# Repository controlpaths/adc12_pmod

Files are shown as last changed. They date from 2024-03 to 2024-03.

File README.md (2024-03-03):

# PMOD ADC12

PMOD with an ADC and an analog circuit to read signals up to +-12V. The PMOD uses the ADC [ADC122S021](https://www.ti.com/lit/ds/symlink/adc122s021.pdf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) from TI.

To read negative signals, the analog circuit inserts an offset voltage before the signal in connected to the ADC. This offset is always VCC/2. 

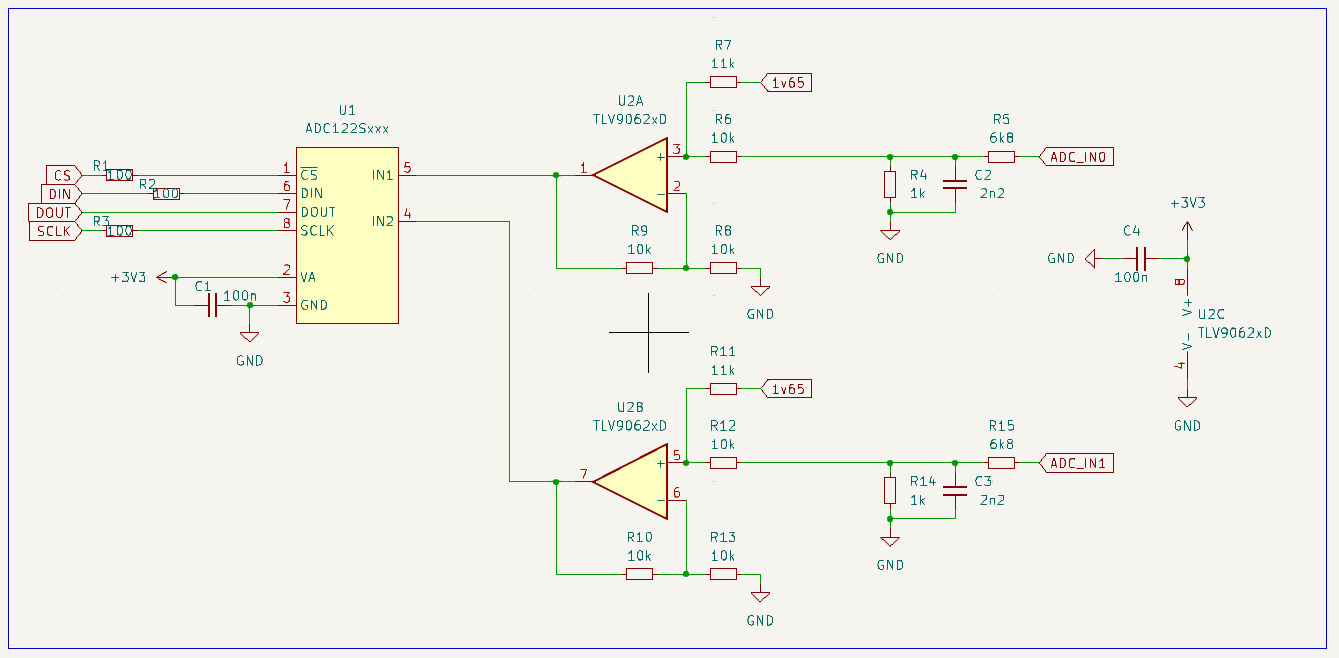
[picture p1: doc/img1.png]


In addition, a first-order low pass filter is added in both input channels.

## PMOD interface

This PMOD uses an SPI interface to read the ADC. The pinout of the board is shown in the next image.

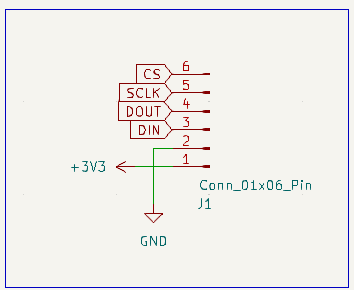
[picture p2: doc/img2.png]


The SPi connection is different than the PMOD SPI standard.

## Images

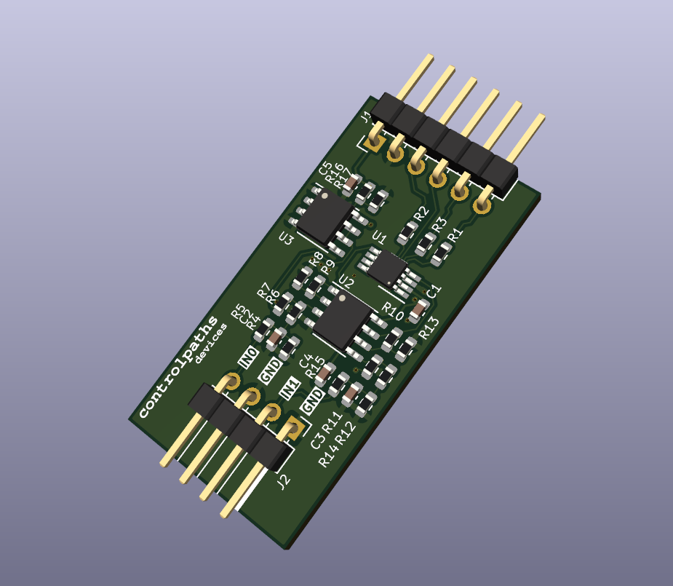
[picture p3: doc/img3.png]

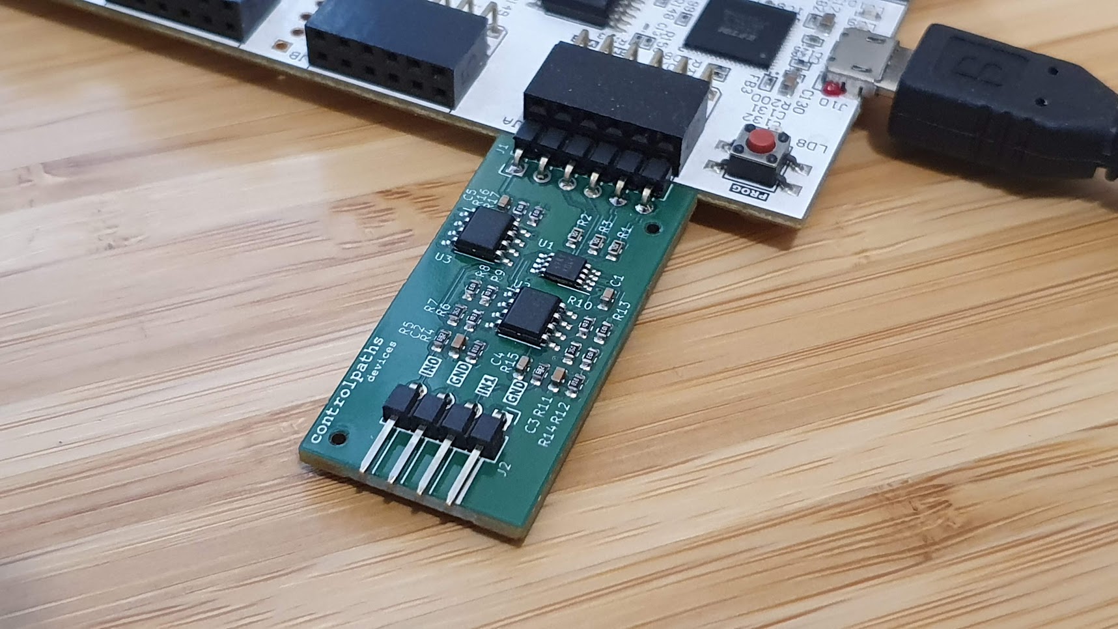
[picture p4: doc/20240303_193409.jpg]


## Get Yours

The PMOD ADC12 is open-source, so you can use the output files to manufacture your own in [JLCPCB](https://jlcpcb.com/?from=controlpath). You just need to compress the `output_files` directory, and upload it to [JLCPCB](https://jlcpcb.com/?from=controlpath). 

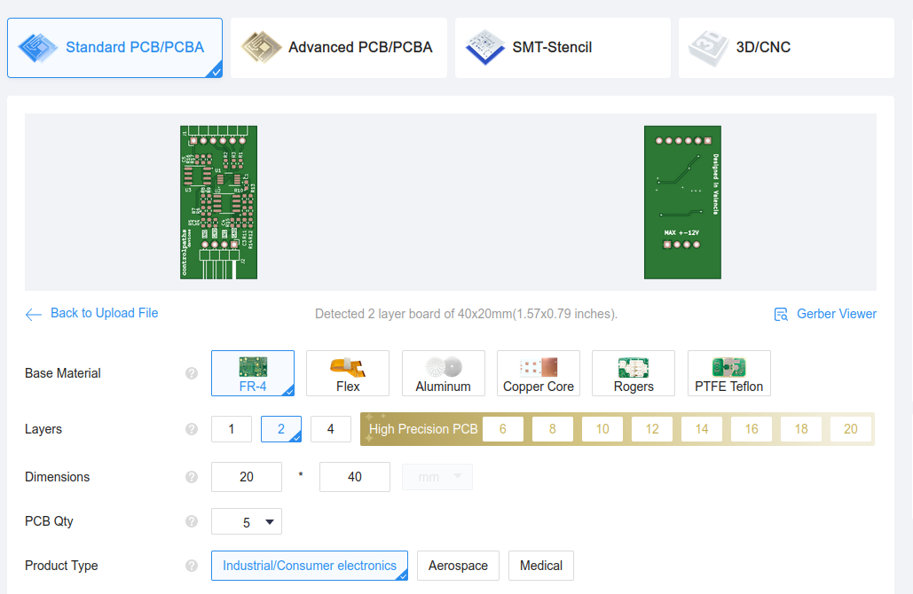
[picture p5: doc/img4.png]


Remember to change the Surface Finish to **LeadFree HASL** to make your board ROHS compliant.

Then you have to add the PCB Assembly service and upload the [centroid](./kicad/output_files/pmod_adc12-all-pos.csv) file, and the [BOM](./kicad/output_files/bom.csv). 

In a few days, you will receive your board at home. If you want just one PMOD ADC12, contact me.

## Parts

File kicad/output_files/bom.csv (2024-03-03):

# | Reference | Qty | Value | Footprint | DNP | JLCPCB Part #
1 | C1, C4, C5 | 3 | 100n | Capacitor_SMD:C_0603_1608Metric
2 | C2, C3 | 2 | 2n2 | Capacitor_SMD:C_0603_1608Metric
3 | J1 | 1 | Conn_01x06_Pin | Connector_PinHeader_2.54mm:PinHeader_1x06_P2.54mm_Horizontal |  | C2894948
4 | J2 | 1 | Conn_01x04_Pin | Connector_PinHeader_2.54mm:PinHeader_1x04_P2.54mm_Horizontal |  | C7501292
5 | R1, R2, R3 | 3 | 100 | Resistor_SMD:R_0603_1608Metric
6 | R4, R14 | 2 | 1k | Resistor_SMD:R_0603_1608Metric
7 | R5, R15 | 2 | 6k8 | Resistor_SMD:R_0603_1608Metric
8 | R6, R8, R9, R10, R12, R13, R16, R17 | 8 | 10k | Resistor_SMD:R_0603_1608Metric
9 | R7, R11 | 2 | 11k | Resistor_SMD:R_0603_1608Metric
10 | U1 | 1 | ADC122Sxxx | Package_SO:VSSOP-8_3.0x3.0mm_P0.65mm |  | C528639
11 | U2, U3 | 2 | TLV9062xD | Package_SO:SOIC-8_3.9x4.9mm_P1.27mm |  | C398355

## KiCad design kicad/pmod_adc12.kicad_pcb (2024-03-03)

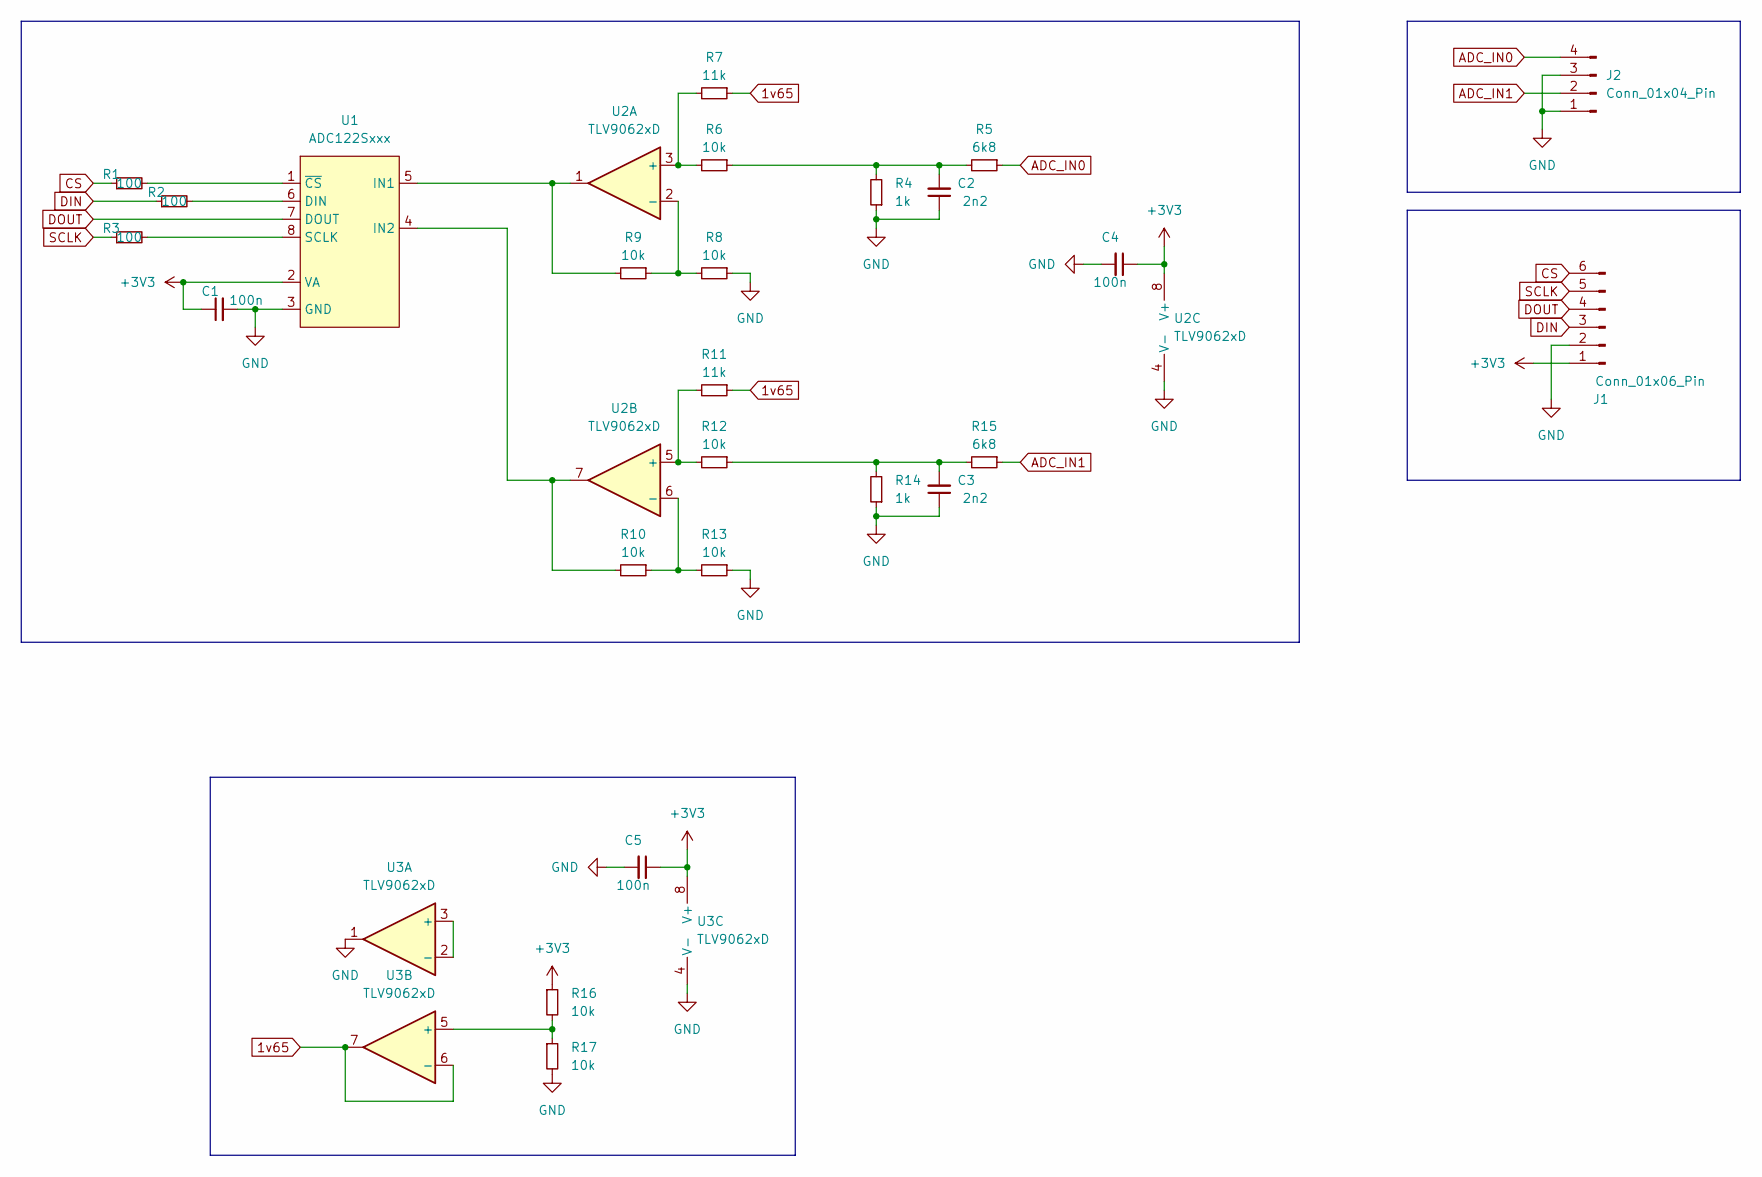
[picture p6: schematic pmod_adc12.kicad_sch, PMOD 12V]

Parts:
C1, C4, C5: 100n; C_0603_1608Metric
C2, C3: 2n2; C_0603_1608Metric
J1: Conn_01x06_Pin; PinHeader_1x06_P2.54mm_Horizontal
J2: Conn_01x04_Pin; PinHeader_1x04_P2.54mm_Horizontal
R1, R2, R3: 100; R_0603_1608Metric
R4, R14: 1k; R_0603_1608Metric
R5, R15: 6k8; R_0603_1608Metric
R6, R8, R9, R10, R12, R13, R16, R17: 10k; R_0603_1608Metric
R7, R11: 11k; R_0603_1608Metric
U1: ADC122Sxxx; VSSOP-8_3.0x3.0mm_P0.65mm; JLCPCB Part # C528639
U2, U3: TLV9062xD; SOIC-8_3.9x4.9mm_P1.27mm; JLCPCB Part # C398355

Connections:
1v65: R7.1, R11.1, U3.6 (-), U3.7
+3V3: C1.1, C4.1, C5.1, J1.1, R16.1, U1.2 (VA), U2.8 (V+), U3.8 (V+)
ADC_IN0: J2.4, R5.1
ADC_IN1: J2.2, R15.1
CS: J1.6, R1.1
DIN: J1.3, R2.1
DOUT: J1.4, U1.7 (DOUT)
GND: C1.2, C2.1, C3.1, C4.2, C5.2, J1.2, J2.1, J2.3, R4.1, R8.1, R13.1, R14.1, R17.2, U1.3 (GND), U2.4 (V-), U3.1, U3.4 (V-)
unnamed: C2.2, R4.2, R5.2, R6.1
unnamed: C3.2, R12.1, R14.2, R15.2
unnamed: R2.2, U1.6 (DIN)
unnamed: R9.2, U1.5 (IN1), U2.1
unnamed: R10.2, U1.4 (IN2), U2.7
unnamed: R3.2, U1.8 (SCLK)
unnamed: R1.2, U1.1 (~CS)
unnamed: R6.2, R7.2, U2.3 (+)
unnamed: R8.2, R9.1, U2.2 (-)
unnamed: R11.2, R12.2, U2.5 (+)
unnamed: R10.1, R13.2, U2.6 (-)
unnamed: U3.2 (-), U3.3 (+)
unnamed: R16.2, R17.1, U3.5 (+)
SCLK: J1.5, R3.1

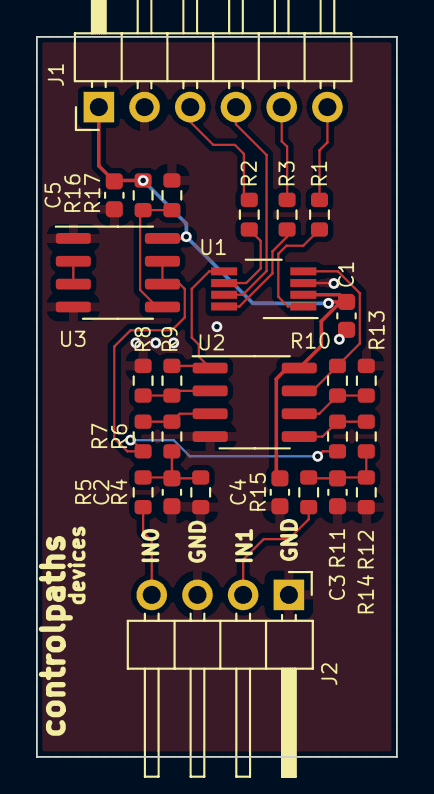
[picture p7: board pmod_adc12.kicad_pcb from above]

Board: 2 copper layers, 20.0 x 40.0 mm, 27 parts (0 on the bottom side), 22 nets.
